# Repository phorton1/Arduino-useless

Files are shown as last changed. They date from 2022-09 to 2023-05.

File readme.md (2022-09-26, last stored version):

# Useless Box

- Servo Arm
- Servo Lid
- 4 x Servo Wheels
- LEDs
- IR Sensors
- Compass (for returning after spin move)

## Session Lifecycle

The box initiates a session with someone the first time the switch is thrown.
A session times out after a period (i.e. 1 minute) of activity.

# types of behaviors

- sneaky fast = no lid, fast move to turn off
- slow = open lid, slowly turn off, slowly reverses
- almost, then = move till almost off, wait, then turn off, fast or slow retreat
- jitter = up to including almost position
- lid jitter = down to and including slapping
- waiting = until hand moves away, and/or some amount of time
- moving = left, right, turn left, turn right, rotate, counter-rotate, find front (with compass)
- front lights are generally white on and black off
- inside lights can be synchronized to each move thing and or flash independently
- ir stuff: besides moves, open door, watch, move arm into position
- lock arm

- outside lights can be indicators, i.e. for ir sensors

// OVERIDING DESIGN CONSIDERATION
//
// Calling neoPixels.show() while servos are attached causes jitter in the servos.
//
// Therefor care must be taken to coordinate the movement of servos with pixel changes.
//
// In general we keep the servos detached when not in use.
// The only place that *might* be a problem is holding up a spring loaded lid.
//
// Jitter is unimportant in the wheels.

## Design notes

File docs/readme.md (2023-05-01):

# Useless Box

**Home** --
**[Electronics](electronics.md)** --
**[Wood](wood.md)** --
**[Top](top.md)** --
**[Bottom](bottom.md)** --
**[Software](software.md)**

For the fun of it, I mada a **Useless Box**.

**Insert YouTube Demo movie here**

All of the **fusion360 files** and the **STL** and **DXF** files exported from fusion, as well as
the **Prusa Slicer** and **Gcode** files and **Lightburn** projects I then used to print the
plastic parts and laser cut the wood can be found in the following subdirecties in the **docs** folder

- **fusion** - the fusion 360 design files
- **stl** - the STL files that I used to slice the plastic parts
- **dxf** - the DXF files that I used to laser cut the wood parts
- **prusa** - the Prusa slicer files and resultant gcode I used to print the plastic parts
- **lightburn** - the Lightburn projects I used to cut the wood.

## Design

I decided on the following basic set of requirements for my useless box

- random **behaviors** - it will be controlled by an arduino nano with various random behaviors
- **mobility** - it will have motors and semi-hidden wheels so it can spin, move left and right, etc
- **sensors** - it will have sensors, probably infrared, to detect when a human tries to touch it
- **leds** - it will have a string of WD2812b leds that will light up the interior for effect and probably some on the top to show the user
- **on-off switch** - it will have an on/off switch to the power supply
- **batteries** - it will use rechargable 18650 Lithium batteries, because I have a bunch of those, and pre-made plastic holders for them
- **nicely constructed** - it will look nice, like a bit of a wood working effort

I had recently upgraded my [**home built cnc machine**](https://github.com/phorton1/Arduino-esp32_cnc20mm) with a new 10W laser, and
had been having a lot of fun making wooden boxes with it, and this seemed like a perfect opportunity to combine that with
some electronics and programming to make something interesting.  I had a bunch of inexpensive **3/16" plywood** that I had
become proficient in cutting and glueing, so I decided the box would be made out of that.

I decided to use small MG90 Servos.  I tested them against a dual 3.7V (7.4V total) 18650 battery pair and, although they get hot
if left running continuously, for short bursts they work ok, and in my application they would not need to be kept running or
holding any positions against any serious forces.  The extra voltage (they are rated at 5V) resulted in extra torque so I felt
that I did not need the much larger kinds of servos that other similar box makers seemed to insist on using.

I also knew that I had bought a number of of "continuous" MG90 servos (by mistake) for an earlier project.  Those turned out to
be perfect for running the motors for the wheels.  I can easily control which way, as well as the speed, each wheel turns with a fair degree
of accuracy.

I decided I would 3D print wheels that made use of some 30mm rubber O-rings that I had.
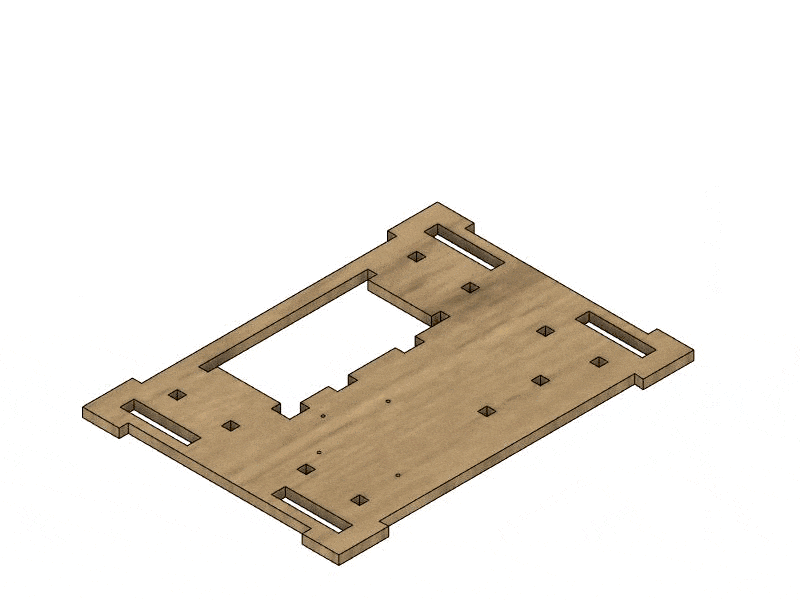
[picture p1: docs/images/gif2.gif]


I used one piece of **1/8" plywood** for the partition.

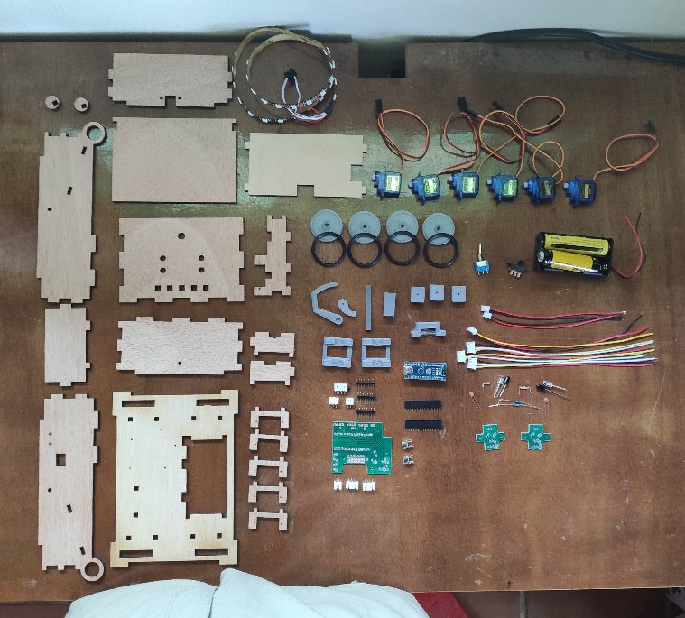
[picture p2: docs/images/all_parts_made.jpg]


### Bill of Materials

- one SPDT blue switch and nut for the top
- one slider SPST switch for the power supply
- a 2 cell 18650 battery holder
- two 90 degree MG90 servos and screws
- four continuous MG90 servos and screws
- four 30x2mm rubber O-rings
- ws2812B LED strip
- two M2x12 screws for the back
- one M3x12 screw for the front
- four or five small screws to hold the main circuit board
- two four wired JST connectors for the sensors
- two two wired JST connectors, one for the power supply, and one for the switch
- two sensor cicruit boards, made below
- one main circuit board, made below
- 3D printed parts, made below
- laster cut wood parts, made below

## Please See

**Please see the following additional pages**

- **[Electronics](electronics.md)** - schematics and circuit boards for the box
- **[Wood](wood.md)** - assembling the wooden box
- **[Top](top.md)** - adding the LEDs, sensors, and switch to the top of the box
- **[Bottom](bottom.md)** - buildling the bottom of the box (Arduino, Batteries, Power Switch, Servos)
- **[Software](software.md)** - a description of the Arduino sketch for the box

## License

This program is free software: you can redistribute it and/or modify
it under the terms of the GNU General Public License Version 3 as published by
the Free Software Foundation.

This program is distributed in the hope that it will be useful,
but WITHOUT ANY WARRANTY; without even the implied warranty of
MERCHANTABILITY or FITNESS FOR A PARTICULAR PURPOSE.  See the
GNU General Public License for more details.

Please see [LICENSE.TXT](https://github.com/phorton1/Arduino-libraries-myIOT/blob/master/LICENSE.TXT) for more information.

**Next:** The [**Electronics**](electronics.md), schematics, and circuit boards used in the box ...

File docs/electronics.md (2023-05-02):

# Useless Box - Electronics

**[Home](readme.md)** --
**Electronics** --
**[Wood](wood.md)** --
**[Top](top.md)** --
**[Bottom](bottom.md)** --
**[Software](software.md)**

Coincident with the fusion *Design* process, I also started some **kicad** projects to
start making the circuit board(s).   I knew the motherboard would be oddly shaped and have to
fit in a limited area, and I also had to work out a layout that would allow me to plug a
USB cable into it for programming, as well as position two buttons so they could be accessed
via toothpicks through the side of the box.

All of the files for the kicad **schematics** and **PCB boards**, as well as the **flatcam**
projects I used, and the **gcode** it produced that I used to etch, paint, drill, and cut
the PCB boards can be found in the **docs/kicad** folder.

### Sensor Boards

At first I thought I would just glue some IR emmitter and reciever diodes into the top of
the box, but decided that it would be better to make some little circuit boards to hold
them (and to allow for some on-board resistors).  Here is the schematic for the sensor
board:

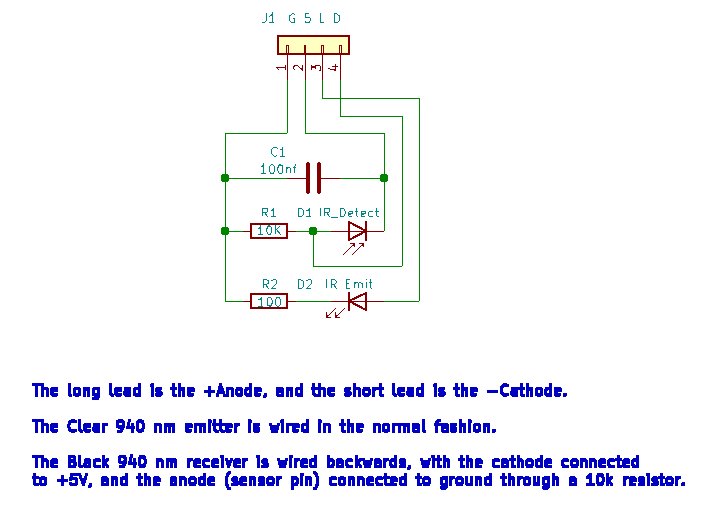
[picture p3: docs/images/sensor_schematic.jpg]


And here is the kicad PCB board:

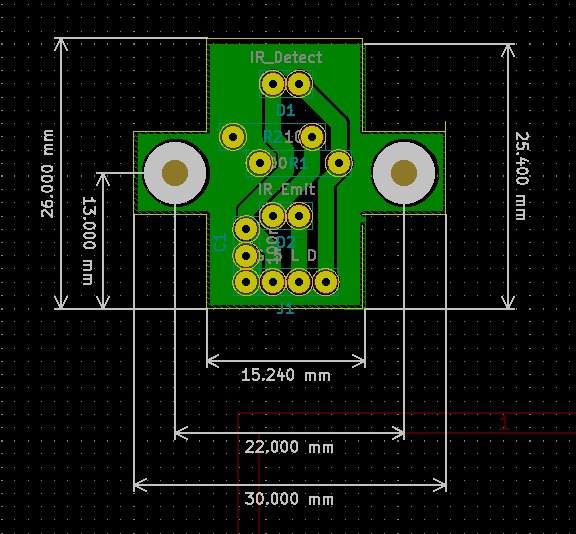
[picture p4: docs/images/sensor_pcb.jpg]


After collecting the parts together ...

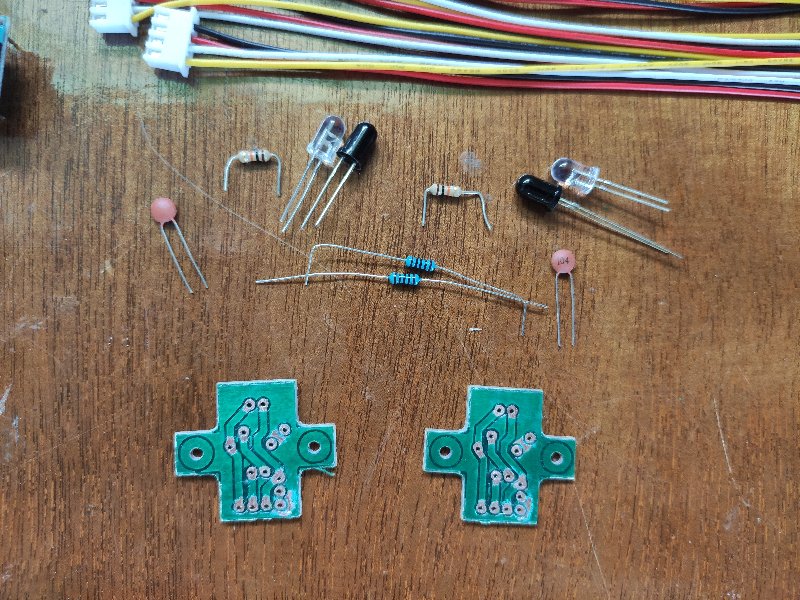
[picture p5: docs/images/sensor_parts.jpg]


I soldered the diodes, capacitor, resistors, and wired JST connector to the boards:

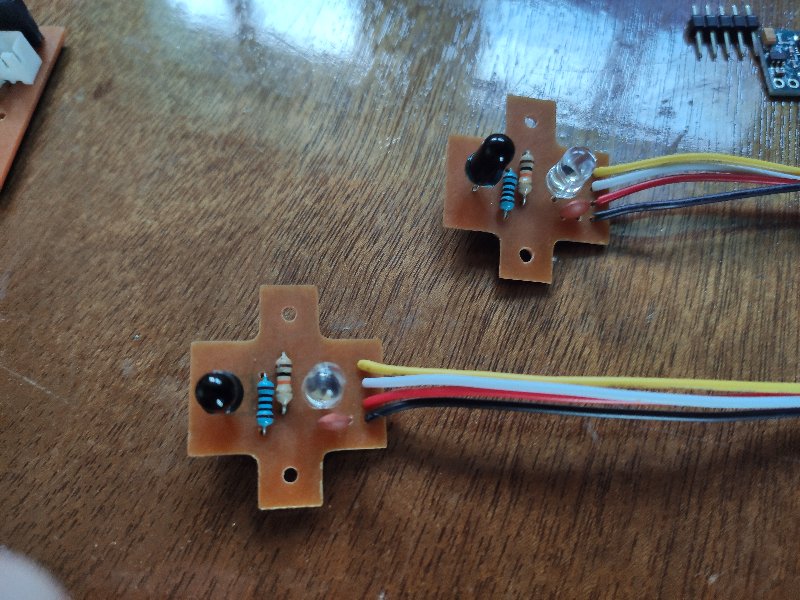
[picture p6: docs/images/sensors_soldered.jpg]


### Main Cicruit Board

Here is the schematic for the circuit board:

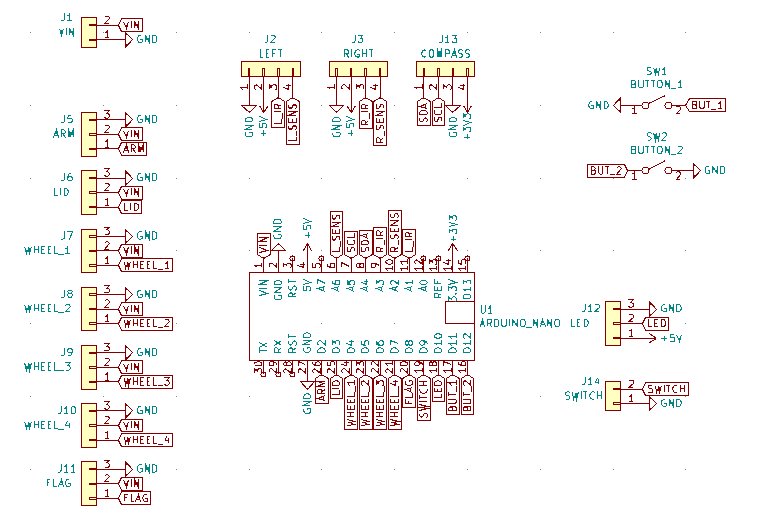
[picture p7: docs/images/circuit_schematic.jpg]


And here is the kicad PCB board:

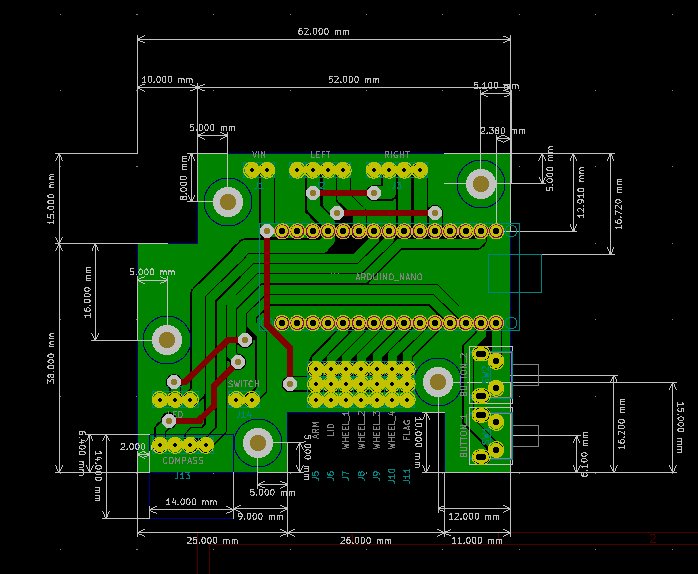
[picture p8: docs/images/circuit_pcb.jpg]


After collecting the parts together ...

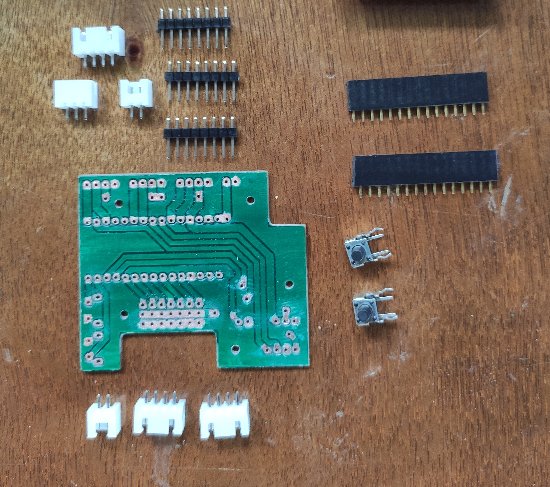
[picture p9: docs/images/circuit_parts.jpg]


I soldered everything (wires, connectors, etc) to the board:

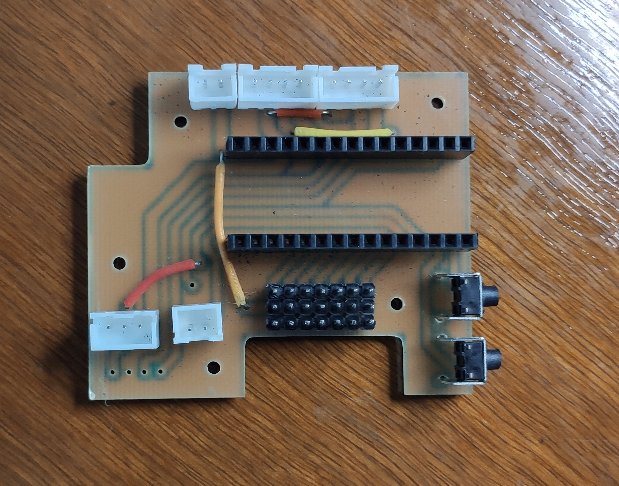
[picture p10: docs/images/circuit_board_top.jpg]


### Solder Switch and LEDs

I also prepared for the assembly by soldering a 2 wire JST connector to
the **switch** and a three wire JST connector the the **LED Strip(s)**.

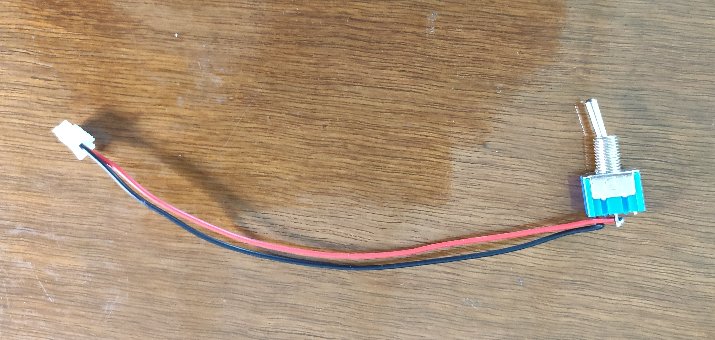
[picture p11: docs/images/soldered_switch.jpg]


The LED Strip is divided into two parts.  The first 6 LEDs will be on the
inside of the box to light up when the lid opens, and the last 5 LEDs will
show through to the user for some kind of a display.

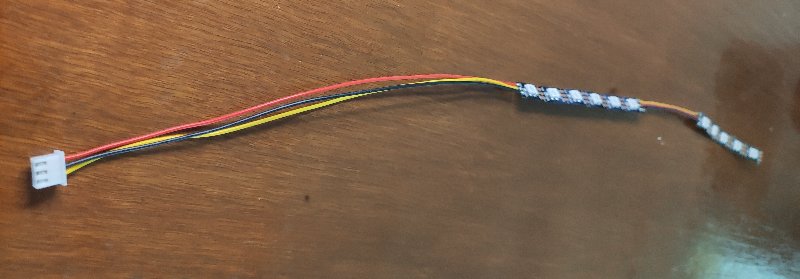
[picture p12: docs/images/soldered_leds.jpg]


**Next:** Constructing the [**Wood**](wood.md) top and bottom of the box ...

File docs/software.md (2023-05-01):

# Useless Box - Software

**[Home](readme.md)** --
**[Electronics](electronics.md)** --
**[Wood](wood.md)** --
**[Top](top.md)** --
**[Bottom](bottom.md)** --
**Software**

One early discovery was that WS2812b LEDs are basically completely incompatible
with most Arduino servo libraries.  If you change the LEDs while the servos are
running, interrupts get turned off while writing to the WS2812s, and the servos
jitter and jump around. After quite a bit of wrangling with the issue, I finally
just gave up and coded the program so that the servos are never running when the
LEDs are changed, and vice-versa.

## Installation/Building

Use **git** or download a **zip** of this repository and place it's contents
in an Arduino *sketch folder* called **useless**.

You will also **require** the following libraries in your Arduino IDE environment

- **[myDebug](https://github.com/phorton1/Arduino-libraries-myDebug)** -
my arduino/teensy/esp32 debug output routines, installed by using **git** or manually installing from
the **[git_repository](https://github.com/phorton1/Arduino-libraries-myDebug)**
- **VarSpeedServo** - installed via the Arduino library manager
- **Adafruit_NeoPixel** - installed via the Arduino library manager

Open the **useless.ino** sketch in the Arduino IDE, then compile and
upload it to the **Arduino Nano**.

## Design

There are many design details, but here I am only going to briefly describe
the **behavioral** aspects of the design.

- There are a set of **acts**.
- The number of acts determines the length of a **pass**.
- Acts made up of **steps**.
- Steps are assigned a minium **pass** they take place in.
- The times, and some of the parameters of an act can be **randomized** between defined limits.

On the first *pass*, the program will go through all the *acts* in order one time.
Starting on the second pass, *acts* are chosen randomly and randomization of parameters begins.
On the second pass **IR mode** (raising the arm as the user's finger gets close to the switch) also begins, randomly, between acts.
Starting on the third pass, **1st level movements steps** within acts (jiggles and shakes) are turned on and once two of those have happened,
we start allowing **full rotations** to occur.  Also at that point we start interpersing random **avoidance modes** along
with the IR mode behavior.

**Please see the source code for more information**

## Closing

I have not done a very good job of documenting this project.

If you are interested in more details, please contact me through github.

Otherwise, I *may* revisit this documentation again someday, but until then ...

**Done!!** [**Back**](readme.md) to the beginning ...

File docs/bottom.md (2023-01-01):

# Useless Box - Bottom

**[Home](readme.md)** --
**[Electronics](electronics.md)** --
**[Wood](wood.md)** --
**[Top](top.md)** --
**Bottom** --
**[Software](software.md)**

Now that we have hooked all the wiring up to the top, we start building the
**bottom** of the box.

### 1. Attach PCB

I start by attaching the PCB using 4-5 M2 screws.  The screws go
directly into the laser cut holes in the wood.

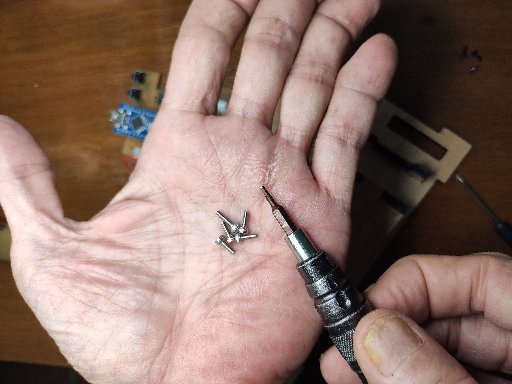
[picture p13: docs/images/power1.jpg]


Adding the PCB first allows me to get the lengths of
the wires for the power connector right.

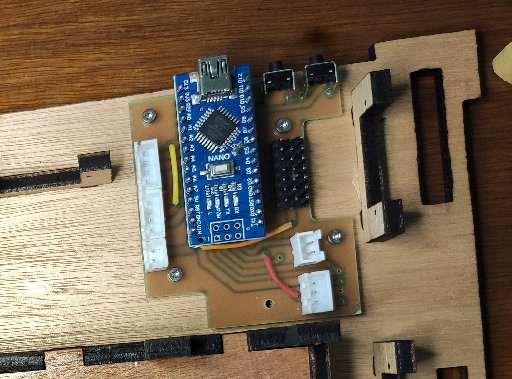
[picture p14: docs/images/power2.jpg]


### 2. Insert Battery Holder and Glue Switch in place

Feed the wires from the battery holder through the holes and
insert the battery holder from the bottom.   Determine the
lengths needed for the power switch and JST connector then cut the wires.

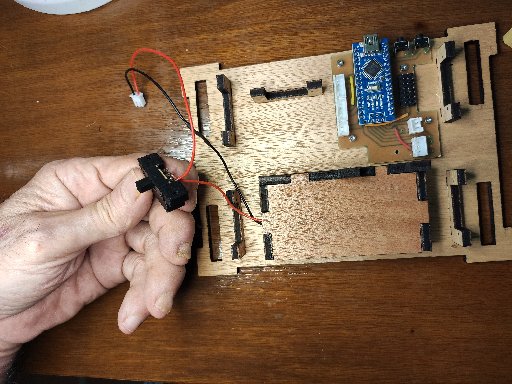
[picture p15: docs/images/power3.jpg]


Strip them and solder the wires and switch together using some heat
shrink tubing to cover the wire solder joints.

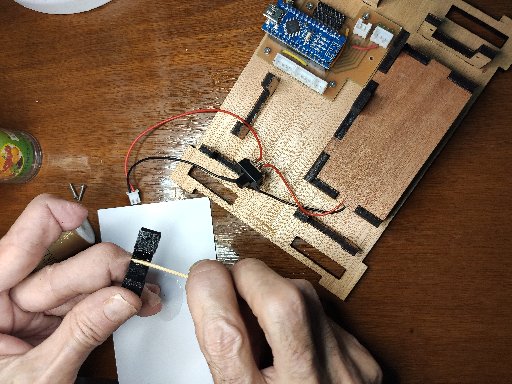
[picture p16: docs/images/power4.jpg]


For lack of a better solution, I then use 5 minute epoxy to glue the
switch into the 3D printed piece, and glue that to the bottom.

**it is important to get the position of the switch correct so that
the top can be attached via two M2 screws on the back!!**.  The only
purpose of the 3D printed piece is to provide screw holes for the top
to attach.

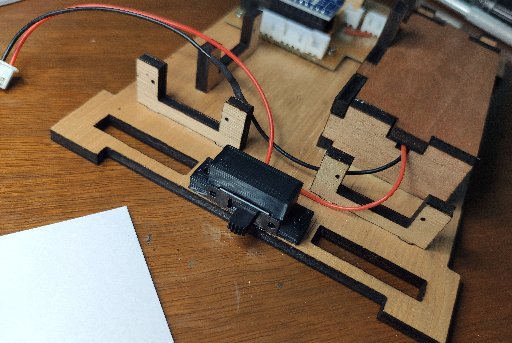
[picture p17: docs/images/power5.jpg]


One alternative way of doing this would be to glue the switch to
the 3D printed part, let that dry, then **screw the assembly to the
top** and **then** put a little glue on the bottom and place the
top on the bottom to get the positioning correct.

Personally, I just eyeballed it to the center, remembering to allow a little
space (1/2 mm) between the top and the bottom and held it in place with
my hand while the 5 minute epoxy set up.

### 3. Install Servos and Route Wires

Attach the control arms and servos for the lid and the arm and
attach the servos to the bottom using the screws that come with
the servos.  *note: I started using **MG90S** servos, with metal
gears, for the arm and lid because, although the 7.4V does not
burn out the motors, the nylon gears are not up to the task of
repeatedly opening the lid and turning the switch off.*

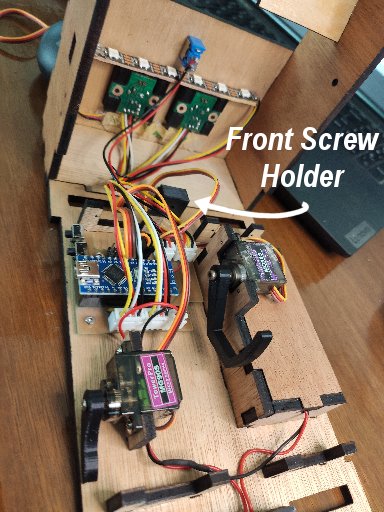
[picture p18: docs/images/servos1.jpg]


I also epoxied the 3D printed **front screw holder** into the
correct place at this point in the process.

As you install the servos it is a good idea to *route* the wires
so that they will not interfere with any of the servos or get
in the way between the top and the bottom.   So I start adding
twist ties at this point in the process as I add each servo.

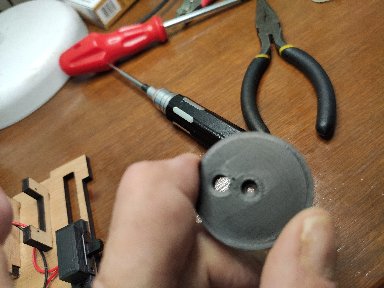
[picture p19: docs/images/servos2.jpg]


Note that **the wheels have a hole in them so that you can
get to the servo mounting screw**.  You put the rubber O-rings
on the wheels, then screw the wheels onto the servos, **then**
mount them on the bottom.   At that point you have something
that looks like the following, and we are nearly done.

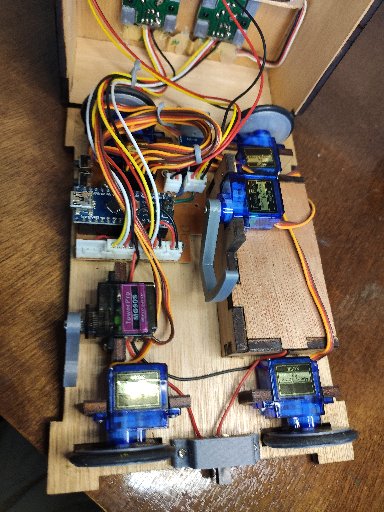
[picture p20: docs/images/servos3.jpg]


### 4.  Assembly Done!

All that is left for the physical assembly is to place the top on
the bottom, insert **two M2 screws** in the back, and **one M3 screw**
in the front and sliding the **lid lift piece** into the guide.

By the time I got to the second box I had already completed the software,
so before closing up the box I did a test, by loading the software on the
Arduino, putting some batteries in it, and making sure everything was working.

**Make sure the lift piece can slide freely in the guide!!**  Also, **you may
need to cut the lift piece to length** so that it sits 2mm or so below the top
when the lift arm is in the **down** position.

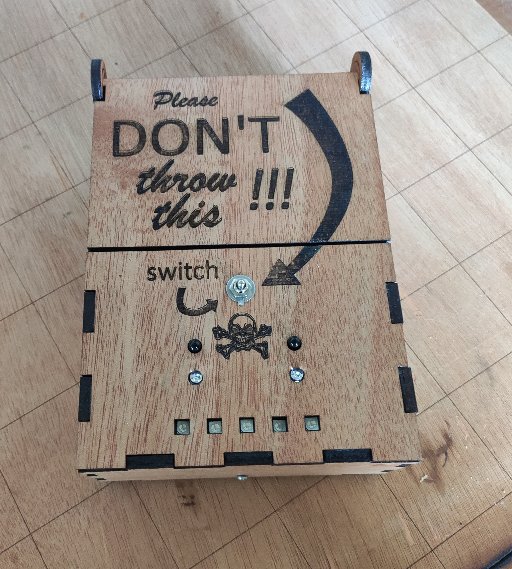
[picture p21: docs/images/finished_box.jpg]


**finished box**

**Next:** Compile and Install the [**Software**](software.md) for the box ...

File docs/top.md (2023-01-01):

# Useless Box - Top

**[Home](readme.md)** --
**[Electronics](electronics.md)** --
**[Wood](wood.md)** --
**Top** --
**[Bottom](bottom.md)** --
**[Software](software.md)**

I do the assembly **starting with the top of the box** to which we
add the LEDs, Sensors, Switch, and Lift-Arm guide.

### 1. Hot Glue LED strip into top

Uhm, the current design has holes for 5 LEDs.  I designed that part without
really thinking it through.  The spacing of the holes does not match the
spacing of the LED strip!!

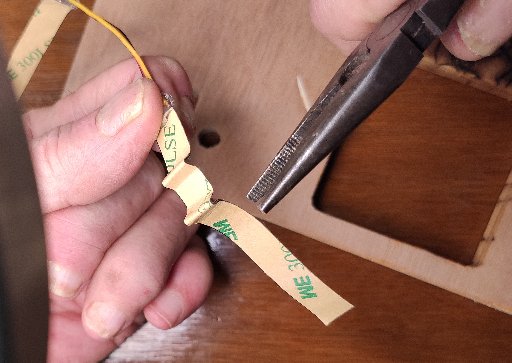
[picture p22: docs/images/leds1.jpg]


A creative implementation solution to this design problem was to **accordian
the LED strip** so that it fit into the 5 holes, then while holding the LEDs
in the holes, hot glue it into place.

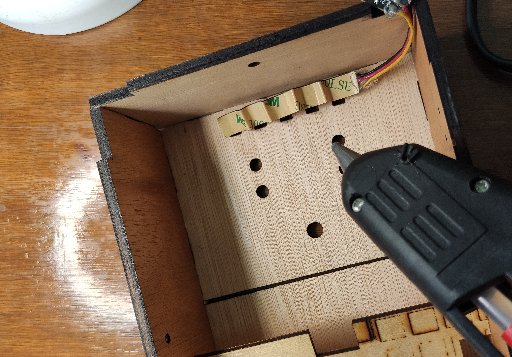
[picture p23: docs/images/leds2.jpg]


*I should probably build a 3rd Useless Box **just** for documentation purposes,
and fix this problem!!  I think 3 LEDs would be sufficient for the top.*

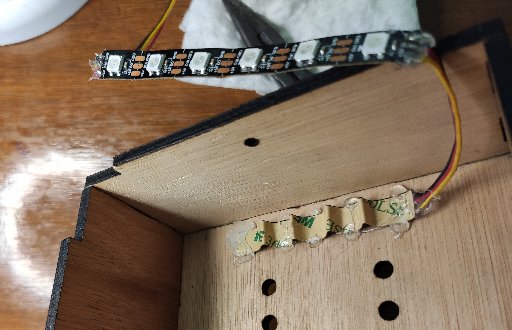
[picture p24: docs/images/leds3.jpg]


### 2. Attach Sensor Boards and Other LED Strip

Using some tiny wood screws, attach the two sensor boards to the 3D printed
pieces.  Then I used 5 minute epoxy to glue those to the top.  This will allow
me to replace the sensor boards if I need to.



After the sensor assemblies are glued to the top, I cut the ends off
a popsicle stick, epoxied that to the front of the sensor plastic, and
used the adhesive on the LED strip to attach them.

### 3. Attach Switch

Attach the switch assembly to the top with it's associated
nut, being careful to align the switch to that it is ON when the
switch is moved UP (and the arm will turn it OFF when the arm hits it).



The top, with it's dangling set of JST connectors, is now nearly finished.



### 4. Epoxy the Lid-Lift guide into place

This is also a good opportunity to epoxy the **lid lift guide**
to the top.



The **lift guide** should be centered in the hole in the partion,
with it's *thinner side* glued to the side of the top.   It should
be about **3-5 mm** from the top of the box so that the arm
can stick out of it a bit, and yet still not contact the top.

**Next:** Assemble the [**Bottom**](bottom.md) main assembly ...

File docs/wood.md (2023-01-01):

# Useless Box - Wood

**[Home](readme.md)** --
**[Electronics](electronics.md)** --
**Wood** --
**[Top](top.md)** --
**[Bottom](bottom.md)** --
**[Software](software.md)**

*note: these pictures are from two different boxes I assembled,
one without any engraving on the outside, and one with engraving.*

I like to finish my laser cut projects with a laquer or enamel clearcoat
as soon after cutting as possible, particularly when there is engraving,
to seal in the burnt carbon, and the images, before I handle them very
much.   I typically finish sand my rough wood before I cut it, once again,
especially if there will be engravings on it.  You don't really want to
sand (or even handle) laser engraved pieces very much before they are
finished or else the black carbon will flake or get rubbed off.

Ideally, after 1-2 coats of clearcoat, with light sanding between, I will
then sand and finish the edges a bit.  I like to sand a 45 degree bevel on
the edges of the wood so that a bright line forms on the side.

In the case of this useless box, I didn't take many pictures of this part
of the process.  I believe I did a single clear coat before glueing anything
together.



**The wood bottom**

Essentially you start by using wood glue to glue the bottom wood pieces together.
The bottom pieces go together very easily, so after gluing, you set that aside to dry.

Gluing the top pieces together is bit of a complicated and hectic process.
**Make sure that everything dry fits before starting!!**  Once you start
putting glue on the bare wood, you have to finish it all in one fell swoop.

You build the top from the left side, starting by inserting the partition piece,
and the back and front at roughly 90 degree angles to the left side. I build it
around the bottom as I go (being careful, of course, to NOT glue the bottom to
the top) to make sure it will all be sort of square when finished.

It's complicated :-)

Before the glue on the left, partition, back, and front sets, you
quickly glue the fixed top piece.  Then **the hardest part**.  While
*somehow holding the whole thing together*, you set the (moveable) **lid** in place,
with it's fingers just floating in the big hinge holes, and you **get the right
side on**.  Press it together and align it all with your hands before gingerly
placing small clamps on it to hold it while the glue dries.



**The wood top**

After that dries, you (sand and) glue the **circular hinge pieces** in place.

You should end up with two pieces ... the bottom, that will hold the
arduino, batteries, and servos, and the top, with a freely moving lid,
that will hold the switch, sensors, and LEDs.

After it is glued, coat 2-5 times with clear laquer or enamel avoiding
getting too much paint into the hinges.

**Next:** Assemble the [**Top**](top.md) by adding the LEDs, sensors, and switch ...

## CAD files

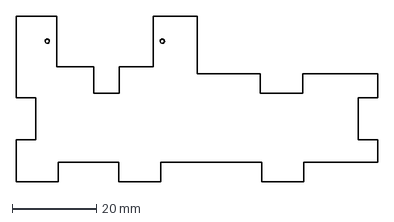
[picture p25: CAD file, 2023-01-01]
docs/dxf/main_mount.dxf
85.8 x 39.3 mm

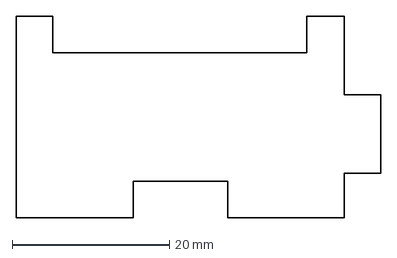
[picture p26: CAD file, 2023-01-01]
docs/dxf/main_front.dxf
46.3 x 25.6 mm

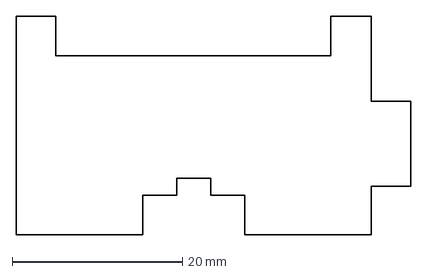
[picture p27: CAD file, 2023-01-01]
docs/dxf/main_back.dxf
46.3 x 25.6 mm

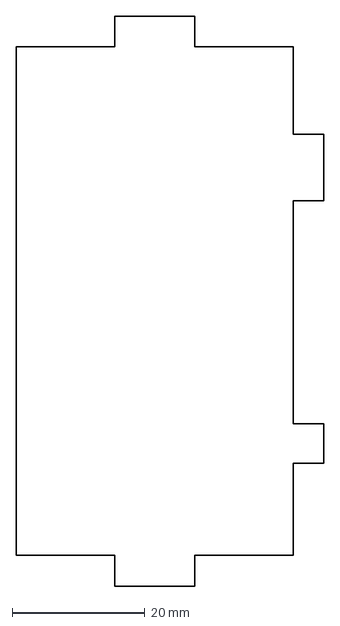
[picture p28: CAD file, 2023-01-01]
docs/dxf/main_top.dxf
46.3 x 85.8 mm

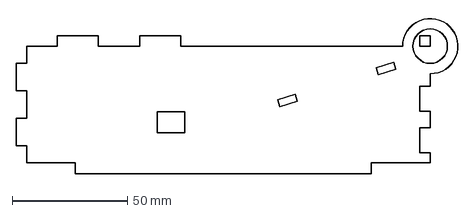
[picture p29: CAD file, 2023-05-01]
docs/dxf/right.dxf
192.9 x 68.3 mm

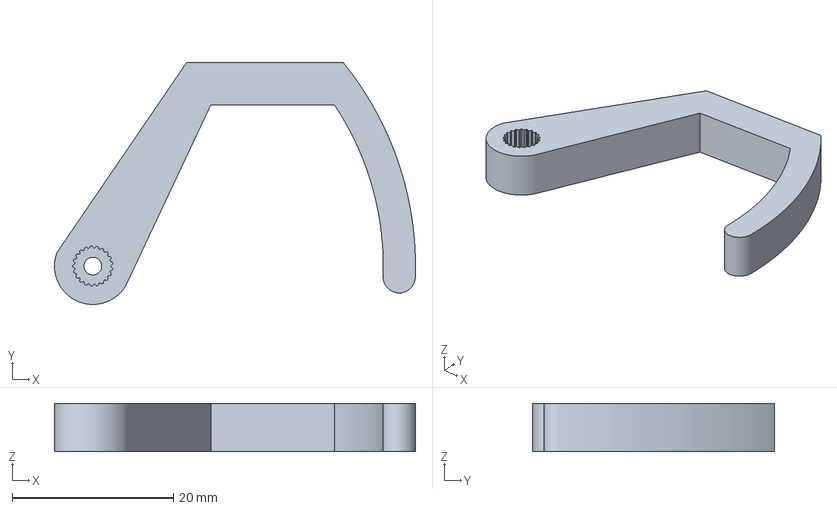
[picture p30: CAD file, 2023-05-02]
docs/prusa/arm.3mf
44.8 x 30.0 x 6.00 mm

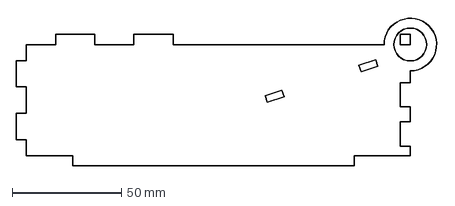
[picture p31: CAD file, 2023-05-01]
docs/dxf/left.dxf
192.9 x 68.3 mm

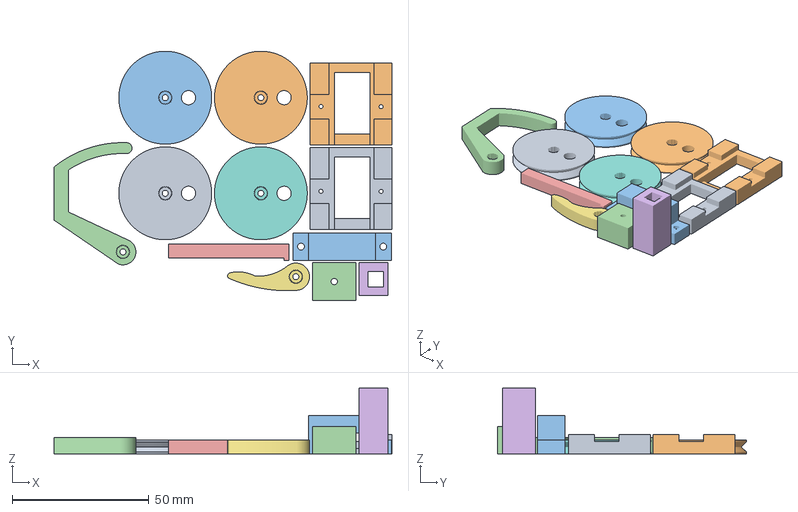
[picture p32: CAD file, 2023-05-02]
docs/prusa/plastic_parts.3mf
123.7 x 91.3 x 24.0 mm
sensor_mount.stl x 2
back_plastic.stl
front_plastic.stl
lid_bar.stl
lid_guide.stl
lid_servo_arm.stl
wheel.stl x 4
arm.stl

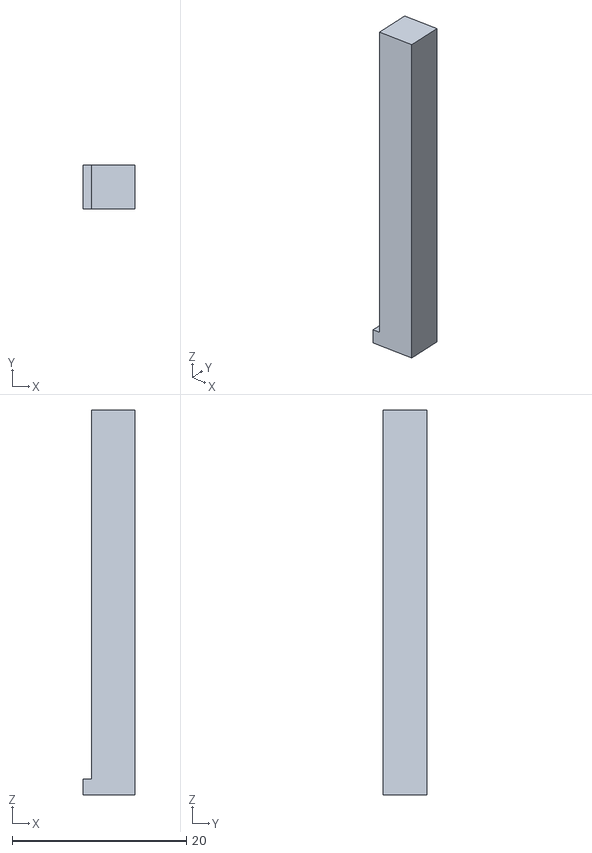
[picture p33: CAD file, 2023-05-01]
docs/stl/lid_bar.stl
6.00 x 5.00 x 44.2

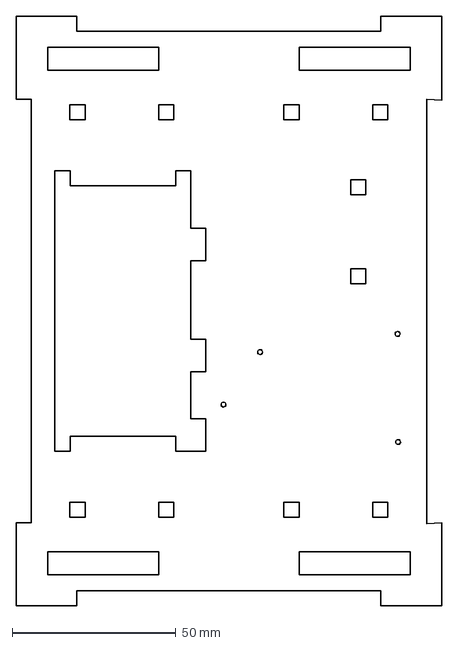
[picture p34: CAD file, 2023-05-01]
docs/dxf/bottom.dxf
130.0 x 180.0 mm

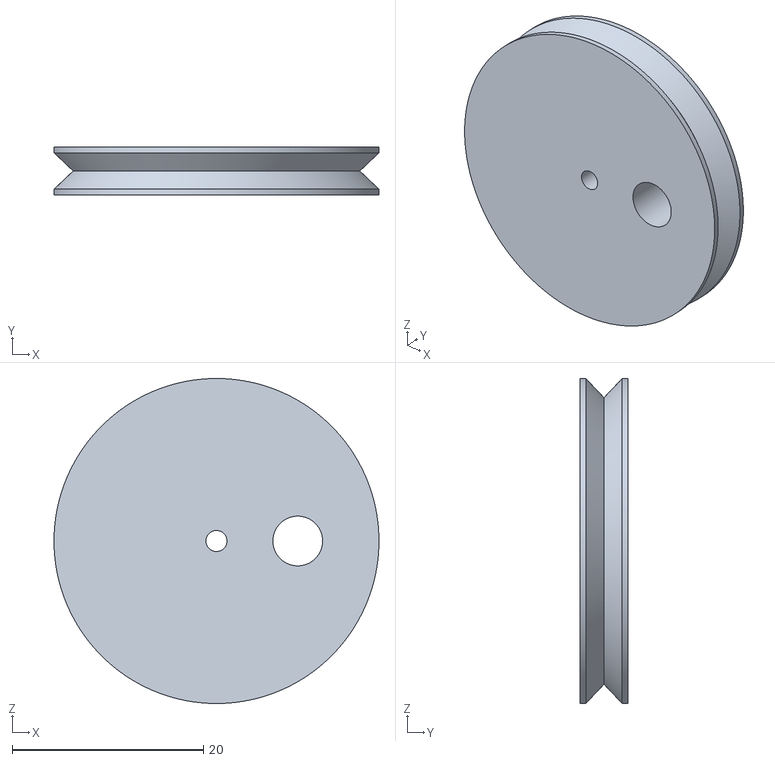
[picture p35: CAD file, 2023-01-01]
docs/stl/wheel.stl
34.0 x 5.00 x 34.0

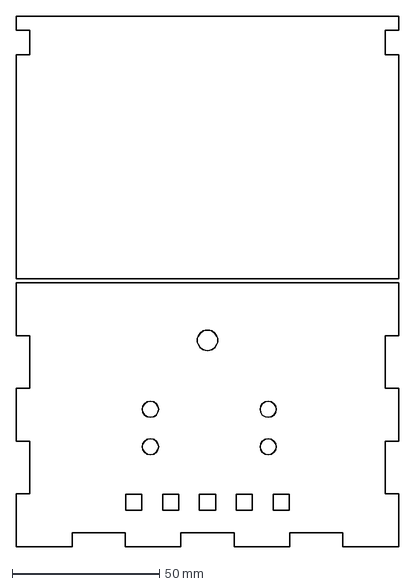
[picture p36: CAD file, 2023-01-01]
docs/dxf/top.dxf
130.0 x 180.0 mm

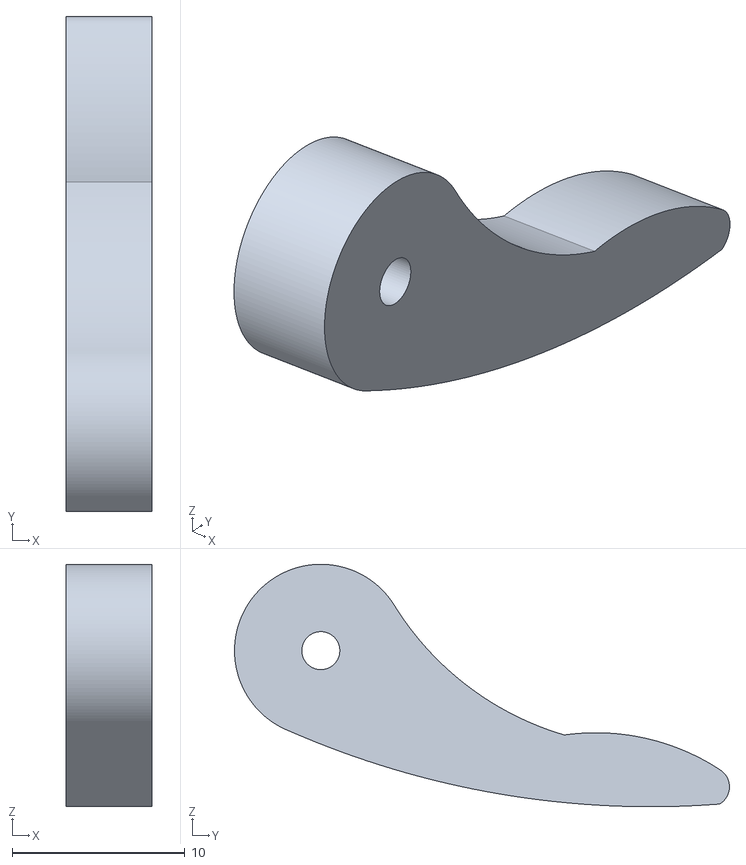
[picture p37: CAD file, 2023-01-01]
docs/stl/lid_arm.stl
5.00 x 28.7 x 14.0

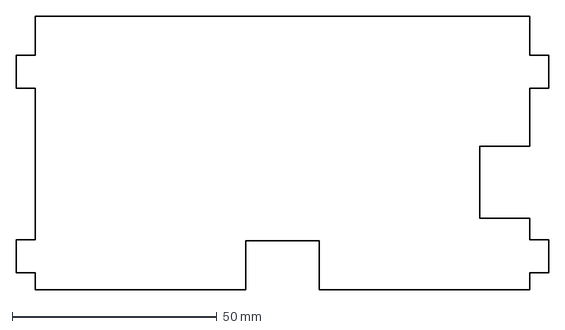
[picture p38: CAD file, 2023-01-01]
docs/dxf/partition.dxf
130.0 x 66.7 mm

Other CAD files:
docs/stl/arm.stl
docs/stl/back_plastic.stl
docs/stl/front_plastic.stl
docs/stl/lid_guide.stl
docs/dxf/back.dxf
docs/dxf/front.dxf
docs/dxf/servo_mount.dxf
docs/fusion/useless_box.f3z
docs/stl/sensor_mount.stl

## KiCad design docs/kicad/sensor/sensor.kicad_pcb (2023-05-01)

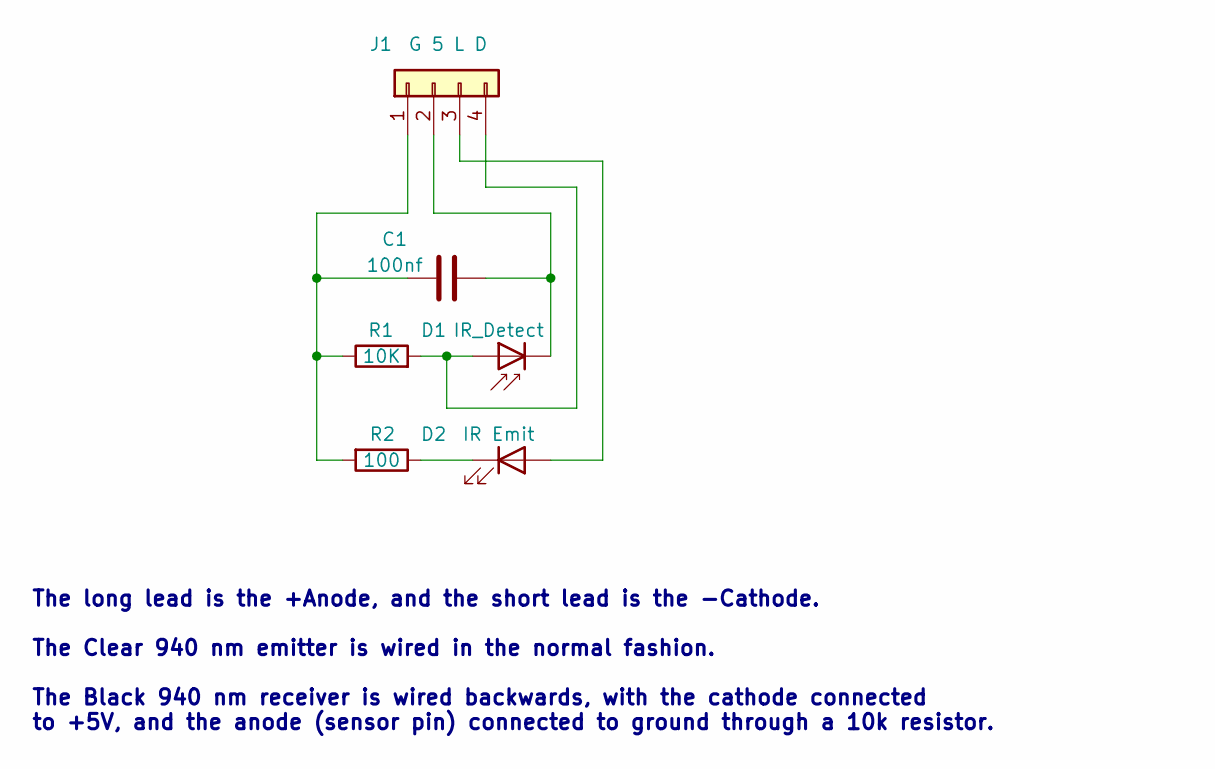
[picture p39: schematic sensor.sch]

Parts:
C1: 100nf; my2pin
D1: IR_Detect; my2pin
D2: IR Emit; my2pin
J1: G 5 L D; my4pin
R1: 10K; myResistor
R2: 100; myResistor

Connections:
+5V: C1.1, D1.1 (K), J1.2
GND: C1.2, J1.1, R1.1, R2.2
unnamed: D1.2 (A), J1.4, R1.2
unnamed: D2.1 (K), R2.1
unnamed: D2.2 (A), J1.3

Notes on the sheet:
The long lead is the +Anode, and the short lead is the -Cathode. The Clear 940 nm emitter is wired in the normal fashion. The Black 940 nm receiver is wired backwards, with the cathode connected to +5V, and the anode (sensor pin) connected to ground through a 10k resistor.

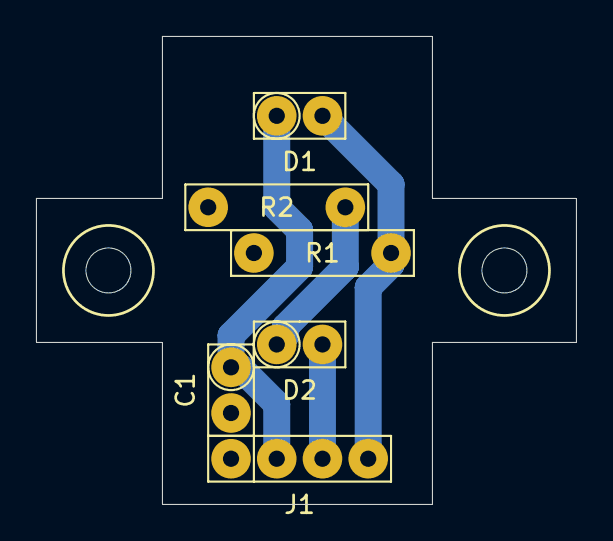
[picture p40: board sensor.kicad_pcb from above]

Board: 2 copper layers, 30.0 x 26.0 mm, 6 parts (0 on the bottom side), 5 nets.

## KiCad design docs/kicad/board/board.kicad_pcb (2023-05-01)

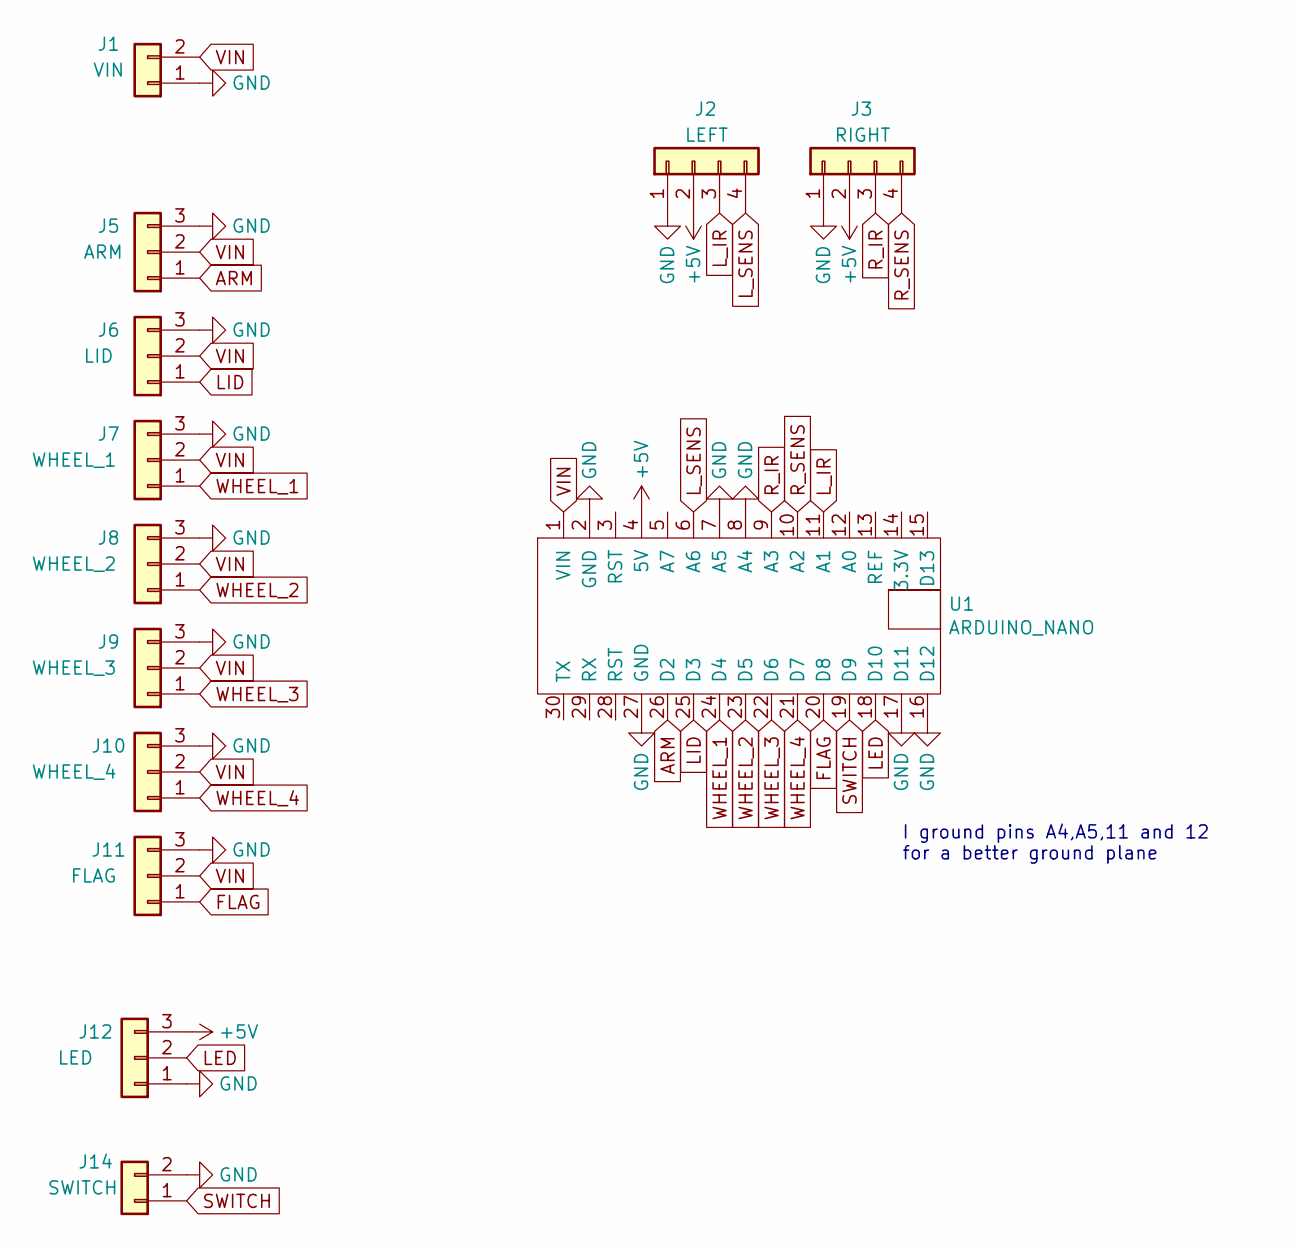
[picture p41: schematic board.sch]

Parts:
J1: VIN; myJSTx02
J2: LEFT; myJSTx04
J3: RIGHT; myJSTx04
J5: ARM; myPinHeader_1x03
J6: LID; myPinHeader_1x03
J7: WHEEL_1; myPinHeader_1x03
J8: WHEEL_2; myPinHeader_1x03
J9: WHEEL_3; myPinHeader_1x03
J10: WHEEL_4; myPinHeader_1x03
J11: FLAG; myPinHeader_1x03
J12: LED; myJSTx03
J14: SWITCH; myJSTx02
U1: ARDUINO_NANO; myArduinoNano

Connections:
+5V: J2.2, J3.2, J12.3, U1.4 (5V)
ARM: J5.1, U1.26 (D2)
FLAG: J11.1, U1.20 (D8)
GND: J1.1, J2.1, J3.1, J5.3, J6.3, J7.3, J8.3, J9.3, J10.3, J11.3, J12.1, J14.2, U1.2 (GND), U1.7 (A5), U1.8 (A4), U1.16 (D12), U1.17 (D11), U1.27 (GND)
LED: J12.2, U1.18 (D10)
LID: J6.1, U1.25 (D3)
L_IR: J2.3, U1.11 (A1)
L_SENS: J2.4, U1.6 (A6)
R_IR: J3.3, U1.9 (A3)
R_SENS: J3.4, U1.10 (A2)
SWITCH: J14.1, U1.19 (D9)
VIN: J1.2, J5.2, J6.2, J7.2, J8.2, J9.2, J10.2, J11.2, U1.1 (VIN)
WHEEL_1: J7.1, U1.24 (D4)
WHEEL_2: J8.1, U1.23 (D5)
WHEEL_3: J9.1, U1.22 (D6)
WHEEL_4: J10.1, U1.21 (D7)

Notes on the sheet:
I ground pins A4,A5,11 and 12 for a better ground plane

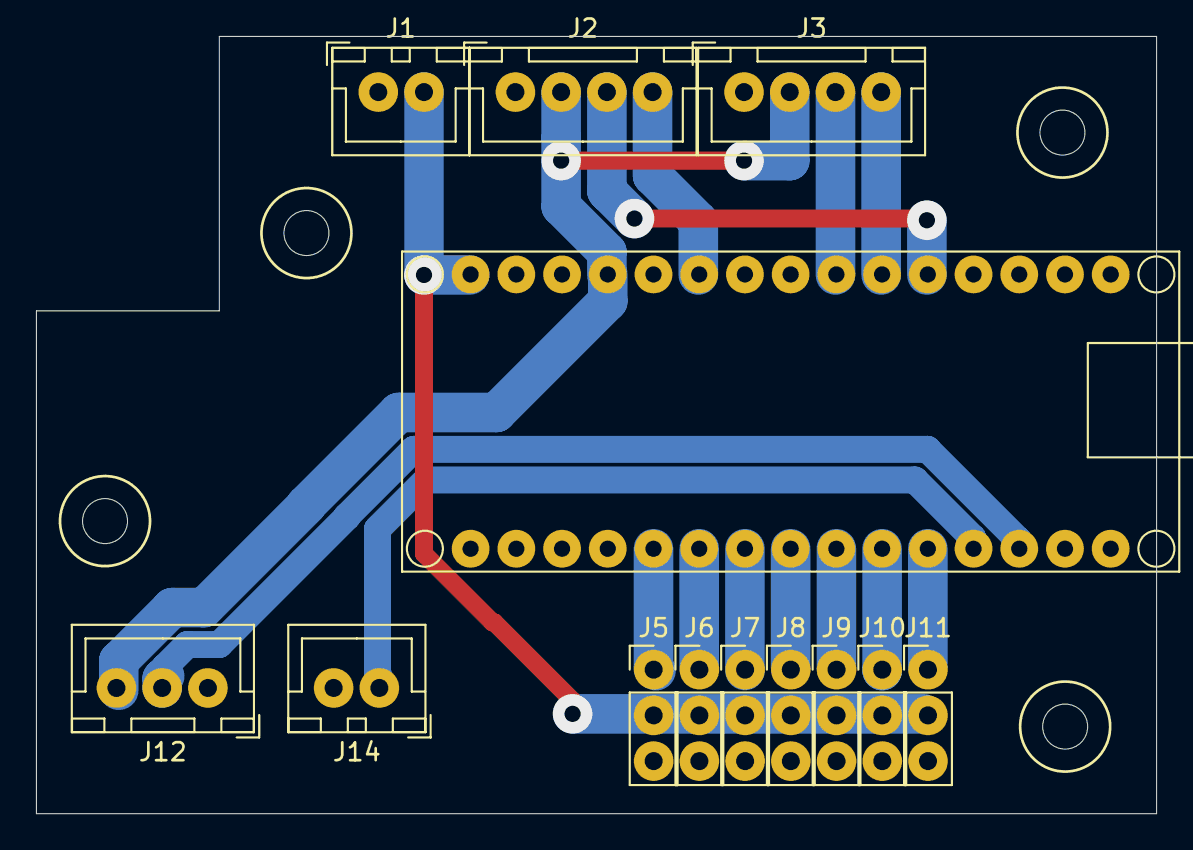
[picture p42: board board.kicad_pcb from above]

Board: 2 copper layers, 62.2 x 43.2 mm, 13 parts (0 on the bottom side), 16 nets.

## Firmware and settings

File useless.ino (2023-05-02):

#include "useless.h"
#include <myDebug.h>
#include "pixels.h"
#include "ir.h"
#include "arm.h"
#include "lid.h"
#include "wheels.h"
#include "acts.h"

// There is quite a bit of variabliity when building one of these.
// I use the MG90S (metal gear) servo for the arm, and if possible, the lid.
// I found that some MG90S's did not return to zero reliably, others did.
// I had to tune the IRs, lid and arm angles, and act speeds to the build.
// Also one nano did not program well with the serial cable.


bool switch_state;
uint32_t frame_time = 0;


void setup()
{
    // JIC - added grounds to these, so I set them to input

    pinMode(A4, INPUT);
    pinMode(A5, INPUT);
    pinMode(11, INPUT);
    pinMode(12, INPUT);

    lid::init();

    Serial.begin(115200);
    delay(200);
    display(0,"useless.ino v1.0 started ...",0);

    randomSeed(analogRead(0));

    #if WITH_PIXELS
        init_pixels();  // leaves row of blue showing
    #endif

    #if WITH_IR
        init_ir();
    #endif

    pinMode(PIN_SWITCH,INPUT_PULLUP);

    arm::init();

    wheels::init();

    #if WITH_PIXELS
        pixels.clear();
        pixels.show();
    #endif
}





void loop()
{
    uint32_t now = millis();
    if (now - frame_time > 50)
    {
        frame_time = now;
        bool sw = digitalRead(PIN_SWITCH) ? 0 : 1;
        if (switch_state != sw)
        {
            switch_state = sw;
            if (sw)
            {
               start_act();
            }
            // else    // turn off lights - done at act endings
            // {
            //     #if WITH_PIXELS
            //         for (int i=0; i<5; i++)
            //             pixels.setPixelColor(PIXEL_USER+i,0,0,0);
            //         pixels.show();
            //     #endif
            // }
        }
        process_act();
    }


    #if WITH_IR
        #if TEST_IR
            static uint32_t last_ir;
            if (now - last_ir >= TEST_IR)
            {
                last_ir = now;
                int tl,tr;
                read_ir(&tl,&tr);
                display(0,"TEST_IR(%d,%d)",tl,tr);
            }
        #endif
    #endif


    #if TEST_MODE
        static int what = 0;
        static int count = 0;
        if (Serial.available())
        {
            int c = Serial.read();
            if (c == 'c')       // cw
            {
                display(0,"wheels::cw(%d)",WHEEL_TIME);
                wheels::cw(WHEEL_TIME);
            }
            else if (c == 'w')  // ccw
            {
                display(0,"wheels.ccw(%d)",WHEEL_TIME);
                wheels::ccw(WHEEL_TIME);
            }
            else if (c == 'r')  //  move to right
            {
                display(0,"wheels::right(%d)",WHEEL_TIME);
                wheels::right(WHEEL_TIME);
            }
            else if (c == 'l')  // move to left
            {
                display(0,"wheels::left(%d)",WHEEL_TIME);
                wheels::left(WHEEL_TIME);
            }
            else if (c == '+')  // rotate clockwise
            {
                display(0,"wheels::rotate_cw(%d)",ROTATE_TIME);
                wheels::cw(ROTATE_TIME);
            }
            else if (c == '-')  // rotate counter clockwise
            {
                display(0,"wheels::rotate_ccw(%d)",ROTATE_TIME);
                wheels::ccw(ROTATE_TIME);
            }
        }
    #endif

    wheels::update();
        // wheel updating has it's own 1ms frame rate
}

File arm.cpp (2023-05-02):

// arm.cpp

#include "arm.h"
#include <VarSpeedServo.h>
#include <myDebug.h>

#define DEBUG_ARM    0

#define ARM_UP_DEGREES 50
#define ARM_OUT_DEGREES 80
#define ARM_POISED_DEGREES 98
#define ARM_OFF_DEGREES 110
#define ARM_TURN_OFF_DEGREES 115


bool arm::m_wait_off;


VarSpeedServo arm_servo;


void arm::init()
{
	arm_servo.attach(PIN_ARM);
	arm_servo.write(0);
	delay(100);
	arm_servo.detach();
}


bool arm::busy()
{
	if (m_wait_off)
	{
		if (!switch_state)
		{
			m_wait_off = false;
		}
	}
	else if (arm_servo.attached() && !arm_servo.isMoving())
	{
		arm_servo.detach();
	}
	return arm_servo.attached() || m_wait_off;
}


// pass thrus for debuggin
bool arm::attached()
{
	return arm_servo.attached();
}
bool arm::moving()
{
	return arm_servo.isMoving();
}
int arm::read()
{
	return arm_servo.read();
}


void arm::stop()
{
	m_wait_off = 0;
	arm_servo.stop();
	arm_servo.detach();
}

void arm::down(uint8_t rate)
{
	arm_servo.attach(PIN_ARM);
	arm_servo.write(0,rate,false);	// don't wait
	#if DEBUG_ARM
		display(0,"arm_down(%d)",0);
	#endif
}

void arm::up(uint8_t rate)
{
	arm_servo.attach(PIN_ARM);
	arm_servo.write(ARM_UP_DEGREES,rate,false);	// don't wait
	#if DEBUG_ARM
		display(0,"arm_up(%d)",ARM_UP_DEGREES);
	#endif
}

void arm::out(uint8_t rate)
{
	arm_servo.attach(PIN_ARM);
	arm_servo.write(ARM_OUT_DEGREES,rate,false);	// don't wait
	#if DEBUG_ARM
		display(0,"arm_out(%d)",ARM_OUT_DEGREES);
	#endif
}

void arm::poised(uint8_t rate)
{
	arm_servo.attach(PIN_ARM);
	arm_servo.write(ARM_POISED_DEGREES,rate,false);	// don't wait
	#if DEBUG_ARM
		display(0,"arm_poised(%d)",ARM_POISED_DEGREES);
	#endif
}

void arm::off_position(uint8_t rate)
{
	arm_servo.attach(PIN_ARM);
	arm_servo.write(ARM_OFF_DEGREES,rate,false);	// don't wait
	#if DEBUG_ARM
		display(0,"arm_off(%d)",ARM_OFF_DEGREES);
	#endif
}

void arm::turn_off_switch(uint8_t rate)
{
	if (switch_state)
	{
		arm_servo.attach(PIN_ARM);
		arm_servo.write(ARM_TURN_OFF_DEGREES,rate,false);	// don't wait
		#if DEBUG_ARM
			display(0,"arm_turn_off(%d)",ARM_TURN_OFF_DEGREES);
		#endif
		m_wait_off = true;
	}
}

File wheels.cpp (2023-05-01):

// wheels.cpp

#include "wheels.h"
#include <VarSpeedServo.h>
#include <myDebug.h>


#define DEBUG_WHEELS 	  0

// Weirdness ...
// For some reason the servo on wheel one has the opposite polarity of
// wheel four (all other wheels) ....



#define WHEEL_LEFT_FRONT  0
#define WHEEL_LEFT_BACK   1
#define WHEEL_RIGHT_BACK  2
#define WHEEL_RIGHT_FRONT 3

#define PIN_WHEEL(w)	(PIN_WHEEL_FL + (w))


uint16_t 	wheels::m_heading;
uint8_t 	wheels::m_duration;
uint32_t 	wheels::m_start_time;


VarSpeedServo wheel_servo[4];


void wheels::init()
{
	for (int i=0; i<4; i++)
	{
		wheel_servo[i].attach(PIN_WHEEL_FL + i);
		wheel_servo[i].write(90);
		delay(100);
		wheel_servo[i].detach();
	}
}




void wheels::update()
{
	uint32_t now = millis();
	if (m_start_time &&
		m_duration != INFINITE_DURATION &&
		now > m_start_time + m_duration * 10)
	{
		#if DEBUG_WHEELS
			display(0,"move end",0);
		#endif
		stop();
	}
}

bool wheels::busy()
{
	return attached();
}

void wheels::stop()
{
	m_start_time = 0;
	for (int i=0; i<4; i++)
	{
		wheel_servo[i].write(90);
		wheel_servo[i].stop();
		wheel_servo[i].detach();
	}
	delay(5);
}


bool wheels::attached()
{
	for (int i=0; i<4; i++)
	{
		if (wheel_servo[i].attached())
			return true;
	}
	return false;
}
bool wheels::moving()
{
	for (int i=0; i<4; i++)
	{
		if (wheel_servo[i].isMoving())
			return true;
	}
	return false;
}
int  wheels::read(uint8_t num)
{
	return wheel_servo[num].read();
}


void wheels::move(const int *dir, uint8_t duration, uint8_t speed, uint8_t rate)
{
	m_duration = duration;

	#if DEBUG_WHEELS
		display(0,"move(%d,%d,%d)",duration,speed,rate);
	#endif

	for (int i=0; i<4; i++)
	{
		int value = 90 + speed * dir[i];
		wheel_servo[i].attach(PIN_WHEEL_FL + i);
		wheel_servo[i].write(value,rate);
	}
	m_start_time = millis();
}


// for some reason on version 1, wheel 1 and wheel4 have opposite polarities
// on version 2 they have the same polarity, but are backwards from version 1

void wheels::left(uint8_t duration, uint8_t speed, uint8_t rate)
{
	const int dir[] = {1,-1,-1,1};
	move(dir,duration,speed,rate);
}

void wheels::right(uint8_t duration, uint8_t speed, uint8_t rate)
{
	const int dir[] = {-1,1,1,-1};
	move(dir,duration,speed,rate);
}
void wheels::cw(uint8_t duration, uint8_t speed, uint8_t rate)
{
	const int dir[] = {1,1,1,1};
	move(dir,duration,speed,rate);
}
void wheels::ccw(uint8_t duration, uint8_t speed, uint8_t rate)
{
	const int dir[] = {-1,-1,-1,-1};
	move(dir,duration,speed,rate);
}

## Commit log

2022-09-25 initial build and test
    [board.kicad_pcb, board.sch, combined.kicad_pcb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]
2022-09-27 basic wheel moves
2022-09-27 implemented "compass mode" and buttons for brightness and mode changes
2022-09-27 generalized randomization scheme, "fixed" homing, implemented first moves (and replaced servo cuz I had my hand on the box and broke the lid plastic gears)
    [lid.cpp, wheels.cpp]
2022-12-08 Built version 2 for Daniel
    [board.kicad_pcb, board.sch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]
2022-12-30 WIP - useless box documentation
    [sensor.sch]
2023-01-01 Added documentation content files
    [arm.stl, back.dxf, back_plastic.stl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]
2023-01-13 created 3D rendering of PCB with my new kicad footprint files
    [board.kicad_pcb, board.sch]
2023-01-15 commit new board schematic using my new symbols and 3D footprints
    [board.kicad_pcb, board.sch]
2023-05-01 SIMPLIFY: got rid of buttons and compass, smaller PCB, all new outputs
    [board.kicad_pcb, board.sch, bottom.dxf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]
2023-05-02 re-plot, build for NOAH
    [arm.3mf, arm.stl, plastic_parts.3mf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]
2023-05-02 BUILD FOR NOAH - tuning to specific IR's, servos, and arduinos
